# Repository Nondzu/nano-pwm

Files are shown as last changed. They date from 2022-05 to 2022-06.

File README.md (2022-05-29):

# nano-pwm
### PC fan controller based on arduino nano

_______________

##### This controller have 3 independent PWM channels with 25 kHz according to PC fan specification.

##### Serial port (9600bps) is use to communicate with  arduino nano. 

##### AT COMMAND:
* set PWM: <br />
`AT+PWM=$value` - set pwm value for all channels<br />
`AT+PWM=($channel, $value)` - set pwm $value for $channel<br />

* read RPM info: <br />
`AT?RPM` - get RPM values from all channels <br />

Each command must finish be new line character `\n`

example:<br />
`AT+PWM=50` - set all channel PWM to 50%<br />
`AT+PWM=(0,90)` - set channel 0 to 90% PWM. <br />
`AT+PWM=(2,50)` - set channel 2 to 50% PWM. <br />
`AT?RPM` - get rpm value from all channels<br />

-------
#### SCHEMATIC:
Schematic will be available soon. PWM and tachometer pins can by connecting directly to arduino. Additional items are not necessary (resistor or transistors).
here is connection info:<br /><br />
FAN PWM (OUTPUT):<br />
 PIN 9 - PWM output for channel 0<br />
 PIN 10 - PWM output for channel 1<br />
 PIN 3 - PWM output for channel 2<br />
<br />
FAN tachometer (INPUT):<br />
 PIN 4 - RPM CHANNEL 0<br />
 PIN 5 - RPM CHANNEL 1<br />
 PIN 6 - RPM CHANNEL 2<br />

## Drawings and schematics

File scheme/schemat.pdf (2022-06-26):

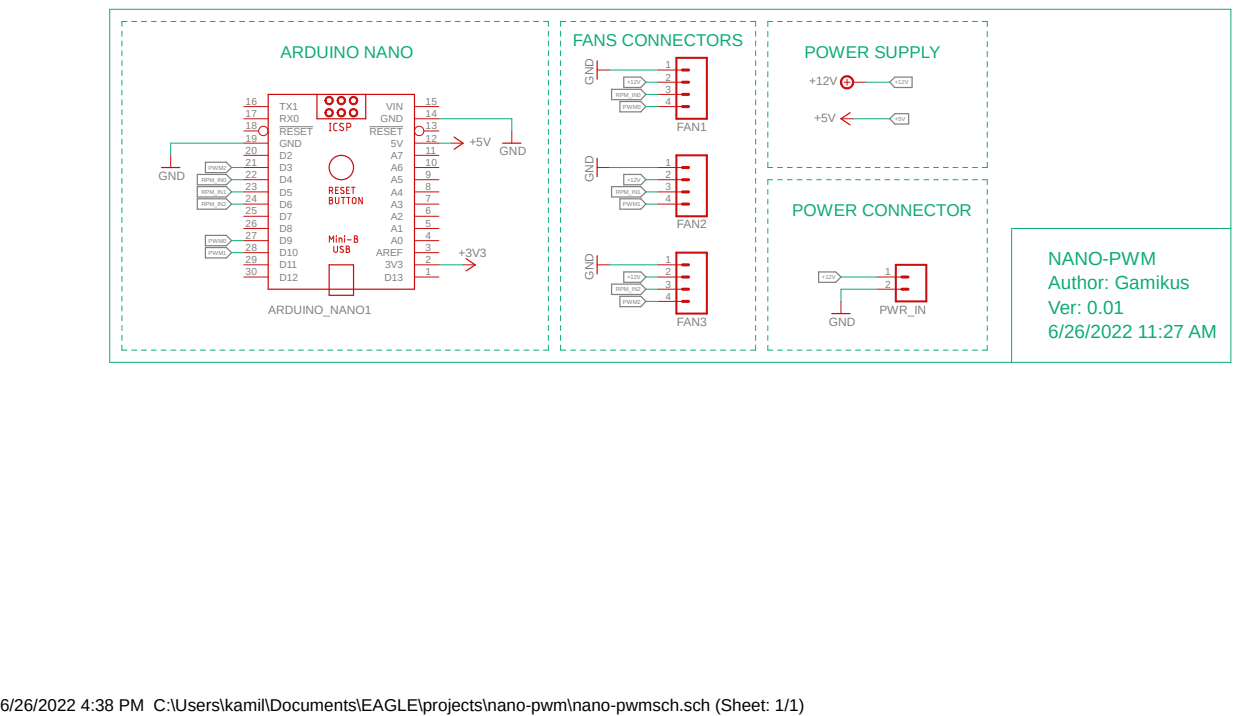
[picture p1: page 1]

6/26/2022 4:38 PM C:\Users\kamil\Documents\EAGLE\projects\nano-pwm\nano-pwmsch.sch (Sheet: 1/1)

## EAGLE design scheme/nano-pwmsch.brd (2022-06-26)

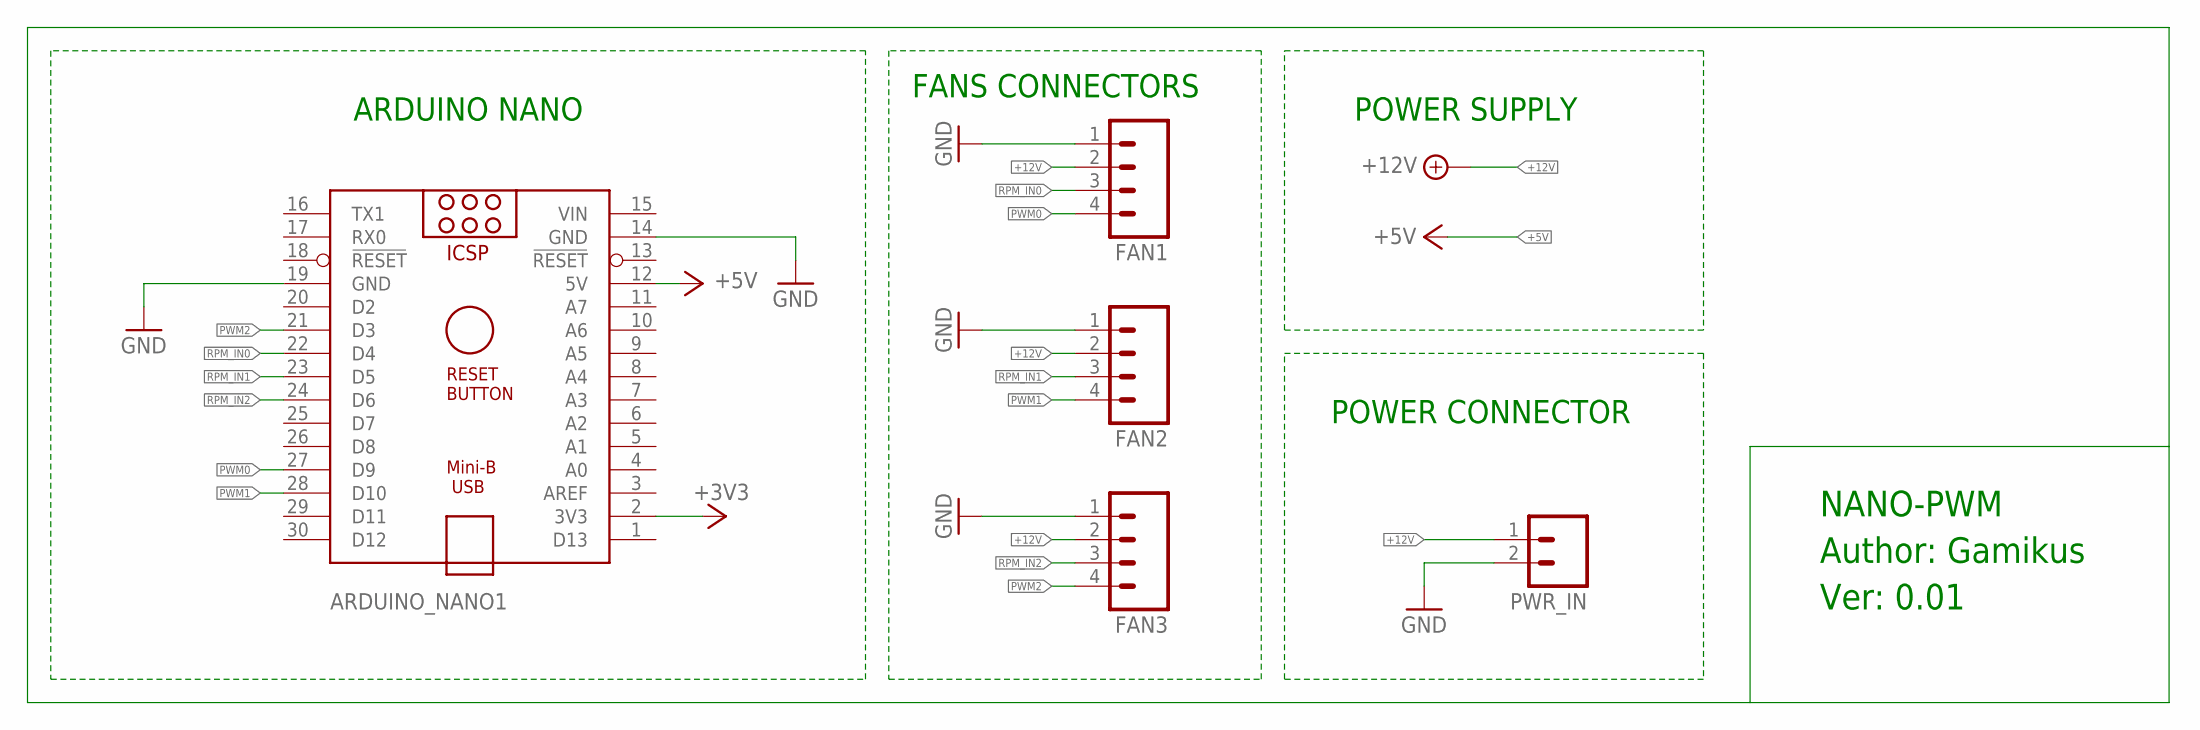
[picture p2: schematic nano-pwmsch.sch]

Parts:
ARDUINO_NANO1: ARDUINO_NANO
FAN1, FAN2, FAN3: M04; 04P
PWR_IN: M02; 02P

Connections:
+3V3: ARDUINO_NANO1.2 (3V3)
+5V: ARDUINO_NANO1.12 (5V)
+12V: FAN1.2, FAN2.2, FAN3.2, PWR_IN.1
GND: ARDUINO_NANO1.14 (GND), ARDUINO_NANO1.19 (GND), FAN1.1, FAN2.1, FAN3.1, PWR_IN.2
PWM0: ARDUINO_NANO1.27 (D9), FAN1.4
PWM1: ARDUINO_NANO1.28 (D10), FAN2.4
PWM2: ARDUINO_NANO1.21 (D3), FAN3.4
RPM_IN0: ARDUINO_NANO1.22 (D4), FAN1.3
RPM_IN1: ARDUINO_NANO1.23 (D5), FAN2.3
RPM_IN2: ARDUINO_NANO1.24 (D6), FAN3.3
VIN: ARDUINO_NANO1.15 (VIN)

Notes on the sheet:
Author: Gamikus
Ver: 0.01
NANO-PWM
ARDUINO NANO
FANS CONNECTORS
POWER SUPPLY
POWER CONNECTOR

Board: 2 copper layers, 5 parts (0 on the bottom side), 8 nets, no tracks yet.

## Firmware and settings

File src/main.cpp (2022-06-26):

#include "Wstring.h"
#include "rpm.h"
#include "at.h"
#include "timers.h"
#include <Arduino.h>
#define LED 13
bool toggle0 = false;

void my1sEvent()
{
    rpmCal(); // to calculate rpm value from FAN tachometer

    digitalWrite(LED, toggle0); //led blink 
    toggle0 = !toggle0; 
}

void setup()
{
    pinMode(LED, OUTPUT);

    rpmInit();
    timerInit();
    timerRegisterCallback(my1sEvent);

    // init serial
    Serial.begin(9600);

    setPWM0(50); // 450
    setPWM1(50); // 840
    setPWM2(50);
}

void loop()
{
    at();
    timer(); // timer function for 1s events
}

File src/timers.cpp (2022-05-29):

#include "timers.h"
#include "rpm.h"
#include "usart.h"
unsigned long previousMillis = 0; // will store last time LED was updated
volatile unsigned long currentMillis = 0;
TimerCallbackPtr timerCallback = nullptr; // timer 1s event callback

void timerRegisterCallback(TimerCallbackPtr callback) { timerCallback = callback; }

void timerInit()
{
    initTimer2();
    initTimer1();
}

void timer()
{
    currentMillis = millis();
    if (currentMillis - previousMillis >= INTERVAL) {
        // save the last time you blinked the LED
        previousMillis = currentMillis;
        if (timerCallback != nullptr) {
            timerCallback();
        }
    }
}

void initTimer0()
{
    // set timer0 interrupt at 2kHz
    TCCR0A = 0; // set entire TCCR2A register to 0
    TCCR0B = 0; // same for TCCR2B
    TCNT0 = 0; // initialize counter value to 0

    // set compare match register for 62.5Hz increments
    // OCR0A = (preskaler 1024) * 250 - 1 =  62.5hz
    OCR0A = 249; // = (16*10^6) / (1024 * 250) - 1 (must be <256)
    OCR0B = 22;
    // turn on CTC mode
    TCCR0A |= (1 << WGM01);
    // Set CS01 and CS00 bits for 1024 prescaler
    TCCR0B |= (1 << CS02) | (1 << CS00);
    // enable timer compare interrupt
    TIMSK0 |= (1 << OCIE0A);
}

void initTimer1()
{
    // Set PWM frequency to  25khz
    TCCR1A = (1 << COM1A1) | (1 << COM1B1) | (1 << WGM11);
    TCCR1B = (1 << CS10) | (1 << WGM13);
    ICR1 = 320;
    OCR1A = 0;
    OCR1B = 0;

    // set pins to output mode
    pinMode(OC1A_PIN, OUTPUT);
    pinMode(OC1B_PIN, OUTPUT);
}

void initTimer2()
{
    // Set PWM frequency to  25khz on pin 3 (timer 2 mode 5, prescale 8, count to 79)
    TIMSK2 = 0;
    TIFR2 = 0;
    TCCR2A = (1 << COM2B1) | (1 << WGM21) | (1 << WGM20);
    TCCR2B = (1 << WGM22) | (1 << CS21);
    OCR2A = 79;
    OCR2B = 0;

    // set pin to output mode
    pinMode(OC2B_PIN, OUTPUT);
}
void setPWM(uint8_t ch, uint8_t pwm)
{
    switch (ch) {
    case 0:
        setPWM0(pwm);
        break;

    case 1:
        setPWM1(pwm);
        break;

    case 2:
        setPWM2(pwm);
        break;

    default:
        setPWM0(pwm);
        setPWM1(pwm);
        setPWM2(pwm);
        break;
    }
}
void setPWM0(uint8_t pwm)
{
    pwm = pwm > 100 ? 100 : pwm;
    OCR1A = (uint16_t)(((uint16_t)320 * pwm) / 100);
    setPwm(0, pwm);
}

void setPWM1(uint8_t pwm)
{
    pwm = pwm > 100 ? 100 : pwm;
    OCR1B = (uint16_t)(((uint16_t)320 * pwm) / 100);
    setPwm(1, pwm);
}

void setPWM2(uint8_t pwm)
{
    pwm = pwm > 100 ? 100 : pwm;
    OCR2B = (uint8_t)(((uint16_t)79 * pwm) / 100);
    setPwm(2, pwm);
}

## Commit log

2022-05-29 1s timer events
2022-05-29 #5 pcint interrupt setup
2022-05-29 #4 rpm calculate
2022-05-29 #11: 3 channels PWM controll
2022-06-26 electronic scheme (Eagle)
    [nano-pwmsch.brd, nano-pwmsch.sch]
